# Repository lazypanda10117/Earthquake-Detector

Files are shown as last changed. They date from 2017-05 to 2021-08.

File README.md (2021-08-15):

## A simple and affordable earthquake detector

<br>

**Brief description of the project**:

We constructed an earthquake detector that can accurately detect earthquakes from affordable equipment, such as gyroscopes and accelerometers. Our core detector and visualization code are written in C (Arduino) and Java (Processing) respectively, while the circuit is designed using Fritzing. These data are stored digitally and analyzed in real-time, which can then be visualized with our graph visualization software. If specific parameters from the analysis are satisfied, the detector will automatically alert people in the surroundings by sounding an alarm. Details about the background, implementation, and cost can be found in the technical report.

<br>

**Technical report**:

[Link to technical report](Report/technical%20report.pdf)

<br>

**Demo**:

Earthquake Detector Demo (http://www.youtube.com/watch?v=r_JWGgkC840 "Earthquake Detector Demo")

<br>

**Contributor**: 

Jeffrey Kam, Joseph Kwon, and Woojin Choi.

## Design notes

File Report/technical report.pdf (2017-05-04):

Earthquake Detector Report Members: Yongjun Kwon, Ho Yin Kam, Woojin Choi Mentor: Brian Mellon

Aim:
Construct an earthquake detector that can detect an earthquake, output the corresponding magnitude of it using a combination of gyroscope and accelerometer data, storing the data digitally, and alert people in the surrounding autonomously.

Abstract:
Researches have been conducted that ants were able to detect an earthquake with the change in gas emission (Hydrogen and Rodon) or by electromagnetic waves. We delved into this topic for further information and how the detection mechanism works. Although there are few significant papers regarding this subject, there are not enough data to reach a conclusion of such mechanism and the research is not able to show a cause and effect relation between gas anomaly and earthquake yet (only correlation has been illustrated). While the research on ants may not be statistically significant for our earthquake detection use, we were inspired by another research conducted by UC Berkeley about using mobile devices to create a distributed network for earthquake detection. As a result, we have resorted to using accelerometer and gyroscope combination to determine the presence of earthquake as we find this way more accurate, cost effective, and intuitive.

Apparatus:
Hardware and Electronics:
Arduino Uno
Arduino Nano
MPU6050 DMP6 (3-Axis Accelerometer and 3-axis gyroscope) GROVE buzzer
3 LED light (Red, Yellow, and Green)
Alwaysoff Vibration Switch (SW-420)
Real Time Clock Module (DST3231)
SD Card Module
Bluetooth Module (HC-05)
Wooden Case (13 cm by 14 cm by 10 cm)

Software:
Arduino Nano software that saves data to sd card and transmits data to computer through Bluetooth module
Arduino Uno software that retrieves data from the MPU6050 and associates the data with the actual data retrieval time using a realtime clock module
Website in javascript that displays the data in graph form.

Documentation/Procedure:
A | working | prototype | is | shown | in | the | following | link:
https://drive.google.com/a/ais.edu.hk/file/d/0B9tS-JHjEeC7NWtzNWlVLTgwYlU/view?usp=drivesdk (https://drive.google.com/a/ais.edu.hk/file/d/0B9tS-JHjEeC7NWtzNWlVLTgwYlU/view?usp=drivesdk)

Electrical Design:
We had to use different hardware materials to finish this earthquake detector and used the Nano Arduino as the mainframe to act and gain data of various components of the machine.The program made for the nano to get the gyroscope/accelerometer was to serve as a motion detector and data to get the roll, yaw, and pitch. The Real Time Clock was used to get the difference in time as milliseconds. The vibrator switch detected if there was a vibration and triggers the buzzer and the LEDs to turn on if the vibration is in accordance with the accelerometer and gyroscope sensor. (i.e. if there is a spike in gyroscope data, it may be some noise or interference. But if we combine with a vibration switch, we can clearly see if the data is a false alarm or not.)

Circuit Board Design:
We have designed a circuit that integrates our whole system into one unified board. This way allow us to organise our connections better and also prevents unexpected errors, such as malfunctioning and loose wires. The top right is the SD card component, connecting to the top
Arduino. The bottom right consists of 4 LEDs,
which are indicators for power, vibration switch,

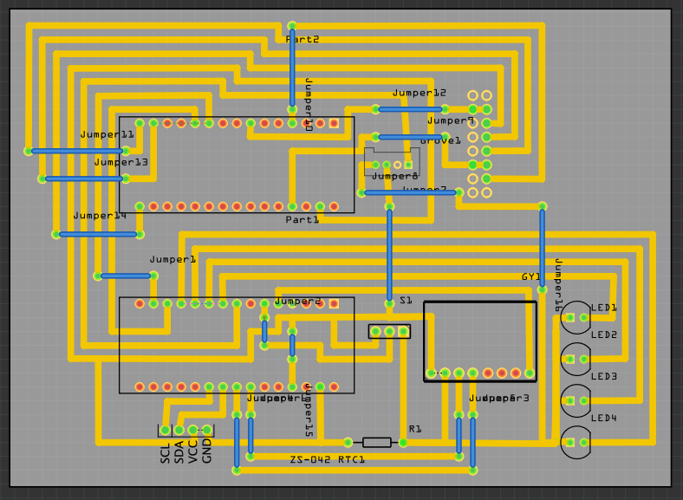
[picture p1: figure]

gyroscope/accelerometer, and earthquake. Next to the LEDs is the MPU 6050, which is connected to the bottom Arduino. The bottom Arduino is attached to the Real Time Clock right below it. After every iteration of code, the data will be compiled and send to the top Arduino using Software Serial using port 10 and 11 and a common GND. The buzzer is connected to the bottom Arduino, so when our program concluded that there might be an earthquake, it will be activated.

Mechanical Design:
We have decided to make a wooden box to put the earthquake detector in because we wouldn't want the machinery to break. The box was made in Maker Bay, a company that sponsored our team. With their contribution, we are able to make a box with their tools for the earthquake detector. All components in the earthquake detector will be placed in the box except the LEDs. With that in mind, we construct a 13x14x10 centimetre wooden box. We made the box by cutting wooden pieces with a blade saw, installing angle connectors, adjusting the box to the right size and sandpapering the box.

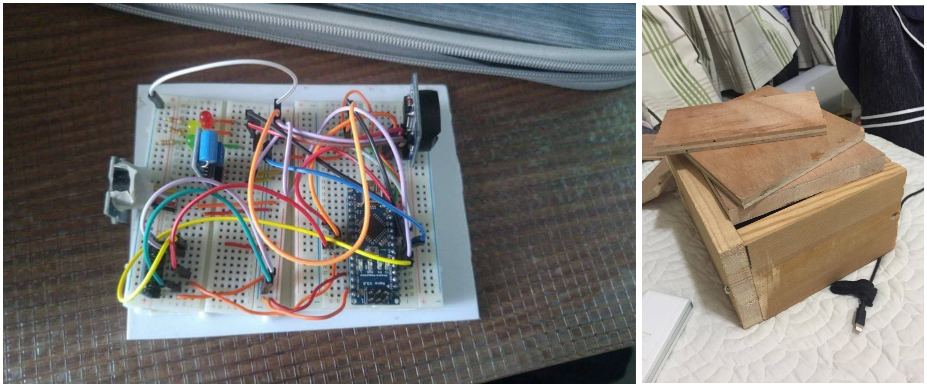
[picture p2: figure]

Software Design
The software is separated into 2 section: the data retrieval and compilation, and the data storing and sending. Mentioned above, we are using two Arduino in our detection system. The two Arduino are connected for data transmission in this following format (time, yaw, pitch, roll, accelerometer x,y,z, average derivative for yaw, pitch roll, x,y,z, magnitude calculated from gyroscope data, magnitude calculated from accelerometer data). The reason we have to separate the system into two Arduino is that Arduino nano does not have enough processing power and ram to run all the calculations regarding the earthquake magnitude, and not enough space to store all the data in our 12 arrays, each storing 12 data entry. Also, even if the board is switched to Arduino Uno, the calculation, data retrieval, and time retrieval take around 0.01-0.03 milliseconds to process, which creates a lot of trouble when we try to log our data as the time will be accumulatively more inaccurate. To transfer data from the Arduino UNO to Arduino nano, we used an internal protocol called the Software Serial, allowing us to transmit around 100 bytes of data every 0.08 seconds. We choose this over I2C for data transmission because I2C has an inherent limitation of 32-bytes of data transferal.

Data retrieval and compilation
We retrieve the data from MPU 6050 using the standardized I2C protocol. When the sensor is first initialized, it is really unstable, so we have devised a code to check the stability of the sensor. If the sensor is stable, the program then continue to retrieve data from our sensors and real time clock; If not, the program will keep looping until the sensor reaches data stability. During data retrieval, we store our data gyroscope yaw, pitch, roll, accelerometer x,y,z, into 6 arrays of length 12. We then calculate the derivative (changes) in between each previous data points, and generate another 6 arrays of length 12 that stores all these calculated derivatives. All these data will be passed through a function that calculates the average value of the array and this value will be sent to another function that determines the magnitude of the earthquake based on our empirically defined constants (shown in “How to measure data and calculate magnitude” section). If this value passes a certain threshold that we define, and this spike of change corresponds to data collected from the vibration switch, we will conclude that there is an earthquake and activate the LEDs and buzzer. A picture of the core algorithm of the program is shown below.

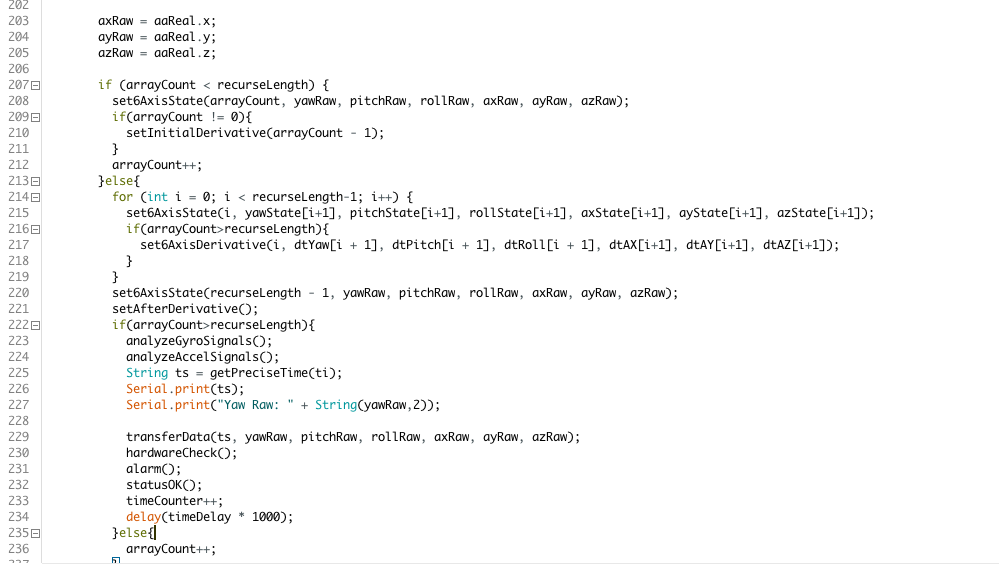
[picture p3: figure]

Data storing and sending
This code is on the top Arduino, running recursively to retrieve all the raw data and calculated derivative arrays from the bottom Arduino. We will first run a preliminary check on the data to make sure the data received are accurate and not some random signal noise. To ensure the integrity of data, we send it in a particular format so that when the program checks the pattern and if it doesn't match, that whole iteration of data entry will be disregarded in our storing process. These data will be compressed and reduced before storing because according to our calculation, we would need an 8gb SD card every month as it generates approximately 300 MB per day. We reduced the data only to have the raw data values and the time of data entry as the derivatives and magnitude can be calculated onthefly as the computer crunches through these massive amounts of data. Through this, we can reduce approximately 60% of the data sent, thus profoundly improving the usability of our system. After storing data, these entries will be broadcasted to the surrounding through Bluetooth using the HC-05 module. A computer can read these data in real time through its internal Bluetooth serial and make use of these realtime data (such as creating a graph of the data or instantaneously send warning to family members).

How to measure data and calculate magnitude:
A | demo | of | the | data | calculation | is | shown | here:
https://drive.google.com/file/d/0B9tS-JHjEeC7X1VtSnVrNmxDQzg/view?usp=sharing (https://drive.google.com/file/d/0B9tS-JHjEeC7X1VtSnVrNmxDQzg/view?usp=sharing)

We measure our data using the MPU 6050 sensors. After data is received and processed (calculating derivative array and average array value), we calculate the earthquake magnitude using the equation:

average derivative = ke

| | | | c(magnitude)

We can rearrange the equation and calculate the average magnitude from our data by changing the formula to:

k

average magnitude = e
c(magnitude)
ln( | ) | (magnitude)
k

average magnitude = c

agnitude
c
ln( | )
k

average magnitude
= m

We devised this equation based on the idea of Richter scale, a logarithmic scale for quantizing the strength of earthquake. We used a combination of some test data and online researches to determine exponential regression line, and use it to find the constants c and k for our equation.

Conclusion
The prototype shows a new and efficient way to detect the earthquake. We used the gyroscope/accelerometer because it is a much efficient way to make data than that of seismographs. We would be able to use a quake alarm where they alarm when an earthquake is coming. However, it can only approximate the magnitude of earthquake based on our limited testing. Based on this approximate magnitude, we can thus estimate how much damage it had caused. This earthquake detector is also economical to build. Researchers has used laser beams and different instruments for the construction of such detector, which are expensive, yet our whole system has only cost us a mere 156 HKD.

Cost:

Item | Cost
Arduino Nano/ uno | 100 HKD
Buzzer | 5 HKD
Accelerometer | 8 HKD
4 LED light | 1 HKD
SD card | 2 HKD
Real Time Clock | 6 HKD
Bluetooth Module | 20 HKD
Vibration Detector | 8 HKD
Circuit board | 6 HKD
Total | 156 HKD

Acknowledgement:
We would like to give special thanks to the following people/ company who have supported us during the course of this competition.
Eunsup Kang
Brian Mellon
Justin Bae
MakerBay

Reference:
December 07, 2010 | 20 Comments. "Earthquake Data Logger." Earthquake Data Logger
SparkFun | Electronics. | N.p., | n.d. | Web. | 24 | Apr. | 2017
<. https://www.sparkfun.com/tutorials/235 >.
"Earthquake Indicator Using Arduino Page 2 of 2." Electronics For You. N.p., 02 Feb. 2017.
Web. | | | 24 | | | Apr. | | | | 2017.
< http://electronicsforu.com/electronicsprojects/hardwarediy/arduinoearthquakeindicator/2 >.
Veedo. "Arduino Seismic Activity Monitor Ethernet Shield." Instructables.com.
Instructables, | 12 | May | 2016. | Web. | 24 | Apr. | 2017.
< http://www.instructables.com/id/Arduino-Seismic-Activity-Monitor-Ethernet-Shield/?ALLS TEPS (http://www.instructables.com/id/Arduino-Seismic-Activity-Monitor-Ethernet-Shield/?ALLSTEPS) >
"Measuring the Size of an Earthquake." U.S. Geological Survey. N.p., n.d. Web. 24 Apr. 2017. < https://earthquake.usgs.gov/learn/topics/measure.php >.
"Hong Kong Observatory." Modified Mercalli Scale. N.p., n.d. Web. 24 Apr. 2017. < http://www.hko.gov.hk/gts/equake/mms_e.htm >.
Berberich, Gabriele, Martin Berberich, Arne Grumpe, Christian Wöhler, and Ulrich Schreiber. "Early Results of Three-Year Monitoring of Red Wood Ants' Behavioral Changes and Their Possible Correlation with Earthquake Events." MDPI. Multidisciplinary Digital
Publishing | Institute, | 04 | Feb. | 2013. | Web. | 24 | Apr. | 2017.
< http://www.mdpi.com/2076-2615/3/1/63/htm (http://www.mdpi.com/2076-2615/3/1/63/htm) >.
"Can Ants Predict When an Earthquake Will Strike?" Local Weather from AccuWeather.com
| Superior | Accuracy™. | N.p., | n.d. | Web. | 24 | Apr. | 2017.
< http://www.accuweather.com/en/weathernews/canantspredictwhenanearth/10211815 (http://www.accuweather.com/en/weather-news/can-ants-predict-when-an-earth/10211815) >. Oskin, Becky. "Ants Lead the Way on Earthquake Prediction." N.p., 11 Apr. 2013. Web. 24 Apr. 2017. < http://www.livescience.com/28672-antssenseearthquakes.html (http://www.livescience.com/28672-ants-sense-earthquakes.html) >.
Zöller, Gert, Sebastian Hainzl, and Jürgen Kurths. "Observation of growing correlation length as an indicator for critical point behavior prior to large earthquakes." Journal of Geophysical
Research: | Solid | Earth. | N.p., | 10 | Feb. | 2001. | Web. | 24 | Apr. | 2017.
< http://onlinelibrary.wiley.com/doi/10.1029/2000JB900379/full >.

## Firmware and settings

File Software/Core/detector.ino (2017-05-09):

#include <SD.h>
#include <SPI.h>
#include "I2Cdev.h"
#include "Wire.h"
#include <RTClib.h>
#include <SoftwareSerial.h>
#include "MPU6050_6Axis_MotionApps20.h"

RTC_DS3231 rtc;
MPU6050 mpu;

#define INTERRUPT_PIN 2

const int buzzerPin = 5;
const int orangeLedPin = 6;
const int greenLedPin = 7;
const int redLedPin = 8;
const int yellowLedPin = 9;

// MPU control/status vars
volatile bool mpuInterrupt = false;     // indicates whether MPU interrupt pin has gone high
bool dmpReady = false;  // set true if DMP init was successful
uint8_t mpuIntStatus;   // holds actual interrupt status byte from MPU
uint8_t devStatus;      // return status after each device operation (0 = success, !0 = error)
uint16_t packetSize;    // expected DMP packet size (default is 42 bytes)
uint16_t fifoCount;     // count of all bytes currently in FIFO
uint8_t fifoBuffer[64]; // FIFO storage buffer

// orientation/motion vars
Quaternion q;           // [w, x, y, z]         quaternion container
VectorInt16 aa;         // [x, y, z]            accel sensor measurements
VectorInt16 aaReal;     // [x, y, z]            gravity-free accel sensor measurements
VectorInt16 aaWorld;    // [x, y, z]            world-frame accel sensor measurements
VectorFloat gravity;    // [x, y, z]            gravity vector
float euler[3];         // [psi, theta, phi]    Euler angle container
float ypr[3];           // [yaw, pitch, roll]   yaw/pitch/roll container and gravity vector
float xyzAccel[3];    
const int accelG = 16384;
//own variables
float prevYpr[3];
float offsetYpr[3]; //initial positions
boolean stable = false;
boolean stableN = false;

double yawRaw;
double pitchRaw;
double rollRaw;

double axRaw;
double ayRaw;
double azRaw;

int arrayCount = 0;
const int recurseLength = 12;
double timeDelay = 0.08;
int timeCounter = 0;
int timeStackToUpload = 3;

long ti; //unix time
String tS; //string unix time
String sdTimeName = "";

double gyroAlarmThreshold = 1.5;
double accelAlarmThreshold1 = 3;
double accelAlarmThreshold2 = 3;
double accelAlarmThreshold3 = 3.8;

double yawState[recurseLength];
double pitchState[recurseLength];
double rollState[recurseLength];

double dtYaw[recurseLength];
double dtPitch[recurseLength];
double dtRoll[recurseLength];

double axState[recurseLength];
double ayState[recurseLength];
double azState[recurseLength];
//end of Setting MPU variables

//equation that model gyroscope magnitude: signal = ke^(c(magnitude))
double expConst = 0.4642; //c
double scaleConst = 1.5578; //k

//equation that model acceleration magnitude: magnitude = a + b(ln(signal))
double baseAccelConst = 7.66395201; //a
double scaleAccelConst = 0.7781699; //b

double mag[3] = {0, 0, 0};
double magA[3] = {0, 0, 0};
double avgD[3] = {0, 0, 0};
double avgA[3] = {0, 0, 0};

File logFile;

void dmpDataReady() {
  mpuInterrupt = true;
}

void setup() {
#if I2CDEV_IMPLEMENTATION == I2CDEV_ARDUINO_WIRE
  Wire.begin();
#elif I2CDEV_IMPLEMENTATION == I2CDEV_BUILTIN_FASTWIRE
  Fastwire::setup(400, true);
#endif
  Serial.begin(115200);
  Serial3.begin(9600);
  if (! rtc.begin()) {
    Serial.println("RTC Failed");
    while (1);
  }
  if (rtc.lostPower()) {
    Serial.println("RTC Failed");
    rtc.adjust(DateTime(F(__DATE__), F(__TIME__)));
  }
  DateTime now = rtc.now();
  sdTimeName = "E";
  String sm = String(now.month());
  if(now.month() < 10){
    sm = "0" + sm;
  }
  String sd = String(now.day());
  if(now.day() < 10){
    sd = "0" + sd;
  }
  sdTimeName += String(now.year()).substring(2,4);
  sdTimeName += sm;
  sdTimeName += sd;
  if (!SD.begin(4)) {
    Serial.println("SD error");
    return;
  }
  mpu.initialize();
  pinMode(INTERRUPT_PIN, INPUT);
  pinMode(buzzerPin, OUTPUT);
  pinMode(yellowLedPin, OUTPUT);
  pinMode(redLedPin, OUTPUT);
  pinMode(greenLedPin, OUTPUT);
  Serial.println(F("Connecting"));
  Serial.println(mpu.testConnection() ? F("Success") : F("Failed"));
  devStatus = mpu.dmpInitialize();
  mpu.setXGyroOffset(220);
  mpu.setYGyroOffset(76);
  mpu.setZGyroOffset(-85);
  mpu.setZAccelOffset(1788);
  if (devStatus == 0) {
    mpu.setDMPEnabled(true);
    attachInterrupt(digitalPinToInterrupt(INTERRUPT_PIN), dmpDataReady, RISING);
    mpuIntStatus = mpu.getIntStatus();
    Serial.println(F("Start"));
    dmpReady = true;
    packetSize = mpu.dmpGetFIFOPacketSize();
  } else {
    Serial.println("MPU Failed");
  }
  for (int i = 0; i < 3; i++) {
    prevYpr[i] = 9999;
  }
}

void loop() {
    if (!dmpReady) return;
    mpuInterrupt = false;
    mpuIntStatus = mpu.getIntStatus();
    fifoCount = mpu.getFIFOCount();
    if ((mpuIntStatus & 0x10) || fifoCount == 1024) {
      mpu.resetFIFO();
    }else if (mpuIntStatus & 0x02) {
      while (fifoCount < packetSize) fifoCount = mpu.getFIFOCount();
      mpu.getFIFOBytes(fifoBuffer, packetSize);
      fifoCount -= packetSize;
      mpu.dmpGetQuaternion(&q, fifoBuffer);
      mpu.dmpGetGravity(&gravity, &q);
      mpu.dmpGetAccel(&aa, fifoBuffer);
      mpu.dmpGetLinearAccel(&aaReal, &aa, &gravity);
      mpu.dmpGetYawPitchRoll(ypr, &q, &gravity);
      if (stable) {      
        yawRaw = ypr[0] * 180 / M_PI;
        pitchRaw = ypr[1] * 180 / M_PI;
        rollRaw = ypr[2] * 180 / M_PI;
        axRaw = aaReal.x-430;
        ayRaw = aaReal.y;
        azRaw = aaReal.z;
        if (arrayCount < recurseLength) {
          set6AxisState(arrayCount, yawRaw, pitchRaw, rollRaw, axRaw, ayRaw, azRaw);
          if(arrayCount != 0){
            setInitialDerivative(arrayCount - 1);
          }
          arrayCount++;  
        }else{
          for (int i = 0; i < recurseLength-1; i++) {
            set6AxisState(i, yawState[i+1], pitchState[i+1], rollState[i+1], axState[i+1], ayState[i+1], azState[i+1]);
            if(arrayCount>recurseLength){
              set3AxisDerivative(i, dtYaw[i + 1], dtPitch[i + 1], dtRoll[i + 1]);
            }
          }
          set6AxisState(recurseLength - 1, yawRaw, pitchRaw, rollRaw, axRaw, ayRaw, azRaw);
          setAfterDerivative();
          if(arrayCount>recurseLength){
            analyzeGyroSignals();
            analyzeAccelSignals();
            String ts = getPreciseTime(ti);
            transferData(ts, yawRaw, pitchRaw, rollRaw, axRaw, ayRaw, azRaw);
            if(!stableN){
              if(magA[1] < 2.5 && magA[2] < 3.5){
                stableN = true;
              }
            }else{
              alarm();
              statusStable();
            }
            statusOK();
            timeCounter++;
            delay(timeDelay * 1000);
          }else{
            arrayCount++;  
          }
        }
        
      } else {
        if (abs(prevYpr[0] - (ypr[0] * 180 / M_PI)) <= 0.01 && abs(prevYpr[1] - (ypr[1] * 180 / M_PI)) <= 0.01 && abs(prevYpr[2] - (ypr[2] * 180 / M_PI)) <= 0.01) {
          delay(3000);
          if (abs(prevYpr[0] - (ypr[0] * 180 / M_PI)) <= 0.01 && abs(prevYpr[1] - (ypr[1] * 180 / M_PI)) <= 0.01 && abs(prevYpr[2] - (ypr[2] * 180 / M_PI)) <= 0.01) {
              Serial.println(ayRaw);
              stable = true;
              for (int i = 0; i < 3; i++) {
                offsetYpr[i] = ypr[i] * 180 / M_PI;
              }
              while(aaReal.y > 60 && aaReal.z > 60){
                delay(50);
              }
          }
        } else {       
          prevYpr[0] = ypr[0] * 180 / M_PI;
          prevYpr[1] = ypr[1] * 180 / M_PI;
          prevYpr[2] = ypr[2] * 180 / M_PI;         
          delay(50);
        }
      }
    }
}

void statusStable(){
  digitalWrite(orangeLedPin,HIGH);
}

void analyzeGyroSignals() {
  //average last recureseLength d(angle)/dt to see which range it is in
  double tempVal1 = 0;
  avgD[0] = averageDerivative(dtYaw);
  avgD[1] = averageDerivative(dtPitch);
  avgD[2] = averageDerivative(dtRoll);
  for (int i = 0; i < 3; i++) {
    tempVal1 = gyroEquation(avgD[i]);
    mag[i] = tempVal1;
  }
}

double gyroEquation(double d){
  return (log((d/scaleConst)+1) / expConst);
}

void analyzeAccelSignals(){
  double tempVal2 = 0;
  avgA[0] = averageDerivative(axState);
  avgA[1] = averageDerivative(ayState);
  avgA[2] = averageDerivative(azState);  
  for (int i = 0; i < 3; i++) {
    tempVal2 = accelEquation(avgA[i]);
    magA[i] = tempVal2;
  }
}

double accelEquation(double d){
  double tD = d/(double)accelG;
  return baseAccelConst + (scaleAccelConst*log(tD));
}

void setInitialDerivative(int i) {
  dtYaw[i] = yawState[i + 1] - yawState[i];
  dtPitch[i] = pitchState[i + 1] - pitchState[i];
  dtRoll[i] = rollState[i + 1] - rollState[i];
}

void setAfterDerivative() {
  dtYaw[recurseLength - 1] = yawState[recurseLength - 1] - yawState[recurseLength - 2];
  dtPitch[recurseLength - 1] = pitchState[recurseLength - 1] - pitchState[recurseLength - 2];
  dtRoll[recurseLength - 1] = rollState[recurseLength - 1] - rollState[recurseLength - 2];
}

void set6AxisState(int id, double y, double p, double r, double ax, double ay, double az) {
  yawState[id] = y;
  pitchState[id] = p;
  rollState[id] = r;
  axState[id] = ax;
  ayState[id] = ay;
  azState[id] = az;
}

void set3AxisDerivative(int id, double dy, double dp, double dr) {
  dtYaw[id] = dy;
  dtPitch[id] = dp;
  dtRoll[id] = dr;
}

double averageDerivative(double d[]) {
  double total = 0;
  for (int i = 0; i < recurseLength; i++) {
    total += abs(d[i]);
  }
  return total / (double)recurseLength;
}

void transferData(String preciseTime, double y, double p, double r, double ax, double ay, double az) {
  String tS = "{" + preciseTime + "," + String(y,2) + "," + String(p,2) + "," + String(r,2) + "," + String(mag[0],2) + "," + String(mag[1],2) + "," + String(mag[2],2) + "," + String(ax,2) + "," + String(ay,2) + "," + String(az,2) + "," + String(magA[0],2) + "," + String(magA[1],2) + "," + String(magA[2],2)+"}";
  String tP =  "{" + preciseTime + "," + String(mag[0],2) + "," + String(mag[1],2) + "," + String(mag[2],2) +  "," + String(magA[0],2) + "," + String(magA[1],2) + "," + String(magA[2],2)+"}";
  //String tA =  "{" + preciseTime + "," + String(magA[0],2) + "," + String(magA[1],2) + "," + String(magA[2],2)+"}";

  if(timeCounter%((int)((timeStackToUpload*100)/(int)(100*timeDelay))) == 0){
    DateTime now = rtc.now();
    ti = now.unixtime();
    timeCounter=0;
  }
  Serial.println(tP);
  Serial3.println(tP);
  putToSDCard(tS);
}

void statusOK() {
  digitalWrite(greenLedPin, HIGH);
}

boolean gyroAlarmCheck() {
  if (mag[0] >= gyroAlarmThreshold || mag[1] >= gyroAlarmThreshold || mag[2] >= gyroAlarmThreshold) {
    digitalWrite(yellowLedPin, HIGH);
    return true;
  }else{
    digitalWrite(yellowLedPin, LOW);
    return false;
  }

}

boolean accelAlarmCheck(){
  if (magA[0] >= accelAlarmThreshold1 || magA[1] >= accelAlarmThreshold2 || magA[2] >= accelAlarmThreshold3){
    digitalWrite(redLedPin, HIGH);
    return true;
  }else{
    digitalWrite(redLedPin, LOW);
    return false;
  }
}

void alarm(){
  boolean a = accelAlarmCheck();
  boolean b = gyroAlarmCheck();
  if(a || b){
    digitalWrite(buzzerPin,HIGH);
  }else{
    digitalWrite(buzzerPin,LOW);
  }
}

String getPreciseTime(long t){
  String tempS = String(t);
  String condition0 = "";
  char cA1[8];
  char cA2[4];
  (tempS.substring(3,10)).toCharArray(cA1,8);
  (tempS.substring(0,3)).toCharArray(cA2,4);
  long tempL1 = atol(cA1);
  int tempL2 = atol(cA2);
  if(tempS.charAt(3) == '0'){
    condition0 = "0";
  }
  long temp = (tempL1*100)+(long)(1.51*(timeDelay*100*timeCounter));
  String tempST = String(temp);
  if(tempST.charAt(0) == '1'){
    tempL2 += 1;
    tempST = tempST.substring(1,10);
  }
  int lenOfTST = tempST.length();
  String finalS = String(tempL2) + condition0 + tempST.substring(0,lenOfTST-2) + "." + tempST.substring(lenOfTST-2,lenOfTST);
  return finalS;
}

void putToSDCard(String s){
  String fileName = sdTimeName + ".txt";
  logFile = SD.open(fileName, FILE_WRITE);
  if (logFile) {
    logFile.println(s);
    logFile.close();
  }else{
    Serial.println("error opening logfile.txt");
  }
}

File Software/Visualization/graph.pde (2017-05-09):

import processing.serial.*;
Serial myPort;  
//PShape square;  
String prev0 = "";
double prev1 = 0;
double prev2 = 0;
double prev3 = 0;
double prev4 = 0;
double prev5 = 0;
double prev6 = 0;
String p0 = "";
double p1 = 0;
double p2 = 0;
double p3 = 0;
double p4 = 0;
double p5 = 0;
double p6 = 0;
double segment = 150;
int widthL = 1280;
int lengthL = 720;
int count = 0;

int midA = (lengthL/4);
int maxA = 10;
int scaleA = midA/maxA;

int midG = 3*(lengthL/4);
int maxG = 8;
int scaleG = midA/maxA;

void setup(){
  //printArray(Serial.list());
  myPort = new Serial(this, Serial.list()[7], 115200);
  size(1280,720);
  background(255);
  stroke(150);
  strokeWeight(3);
  line(0,lengthL/2, widthL, lengthL/2);
  strokeWeight(1);
  line(0,lengthL/4, widthL, lengthL/4);  
  line(0,3*(lengthL/4), widthL, 3*(lengthL/4));  
  fill(0);
  textSize(12);
  text("Unix Time (s): ", 0, 20);
}

void draw(){
  while (myPort.available() > 0) {
    String inBuffer = "";
    char c = myPort.readChar();
    inBuffer += c;
    while(c!='}' && myPort.available() > 0){
      c = myPort.readChar();
      inBuffer += c;
    }
      try{
        if(inBuffer.charAt(0) == '{'){
          String tempS = inBuffer.substring(1,inBuffer.length()-1);
          String sa[] = split(tempS,",");
          p0 = sa[0];
          p1 = Double.parseDouble(sa[1]);
          p2 = Double.parseDouble(sa[2]);
          p3 = Double.parseDouble(sa[3]);
          p4 = Double.parseDouble(sa[4]);
          p5 = Double.parseDouble(sa[5]);
          p6 = Double.parseDouble(sa[6]);
          plotGraph(p0, p1,p2,p3,p4,p5,p6,count);
          prev0 = p0;
          prev1 = p1;
          prev2 = p2;
          prev3 = p3;
          prev4 = p4;
          prev5 = p5;
          prev6 = p6;
        }
      }catch(Exception e){
        plotGraph(prev0, prev1,prev2,prev3,prev4,prev5,prev6,count);
      }
      
      println(inBuffer);
    }
  if(count%2 == 0){
    noStroke();
    fill(255);
    rect(0 + textWidth("Unix Time (s): "),10,textWidth("1231231231231.14"),14);
  }
  if(count > segment){
    background(255);
    stroke(150);
    strokeWeight(3);
    line(0,lengthL/2, widthL, lengthL/2);
    strokeWeight(1);
    line(0,lengthL/4, widthL, lengthL/4);  
    line(0,3*(lengthL/4), widthL, 3*(lengthL/4));
    fill(0);
    textSize(12);
    text("Unix Time (s): ", 0, 20);
    count = 0;
  }
}

void plotGraph(String t, double a, double b, double c, double d, double e, double f, int g){

  fill(0);
  textSize(12);
  text(t,0 + textWidth("Unix Time (s): "), 20);
  //println(t);
  double x1 = (g-1)*((double)widthL/segment);
  double x2 = g*((double)widthL/segment);

  strokeWeight(1.2);
  //gyroscope
  stroke(204, 102, 0); //red
  line((float)x1,(float)(midA-scaleA*prev1),(float)x2,(float)(midA-scaleA*a));
  stroke(150, 230, 128); //green 
  line((float)x1,(float)(midA-scaleA*prev2),(float)x2,(float)(midA-scaleA*b));
  stroke(0, 143, 134); //blue
  line((float)x1,(float)(midA-scaleA*prev3),(float)x2,(float)(midA-scaleA*c));
  //accelerometer
  stroke(204, 102, 0); //red
  line((float)x1,(float)(midG-scaleG*prev4),(float)x2,(float)(midG-scaleG*d));
  stroke(150, 230, 128); //green
  line((float)x1,(float)(midG-scaleG*prev5),(float)x2,(float)(midG-scaleG*e));
  stroke(0, 143, 134); //blue
  line((float)x1,(float)(midG-scaleG*prev6),(float)x2,(float)(midG-scaleG*f));
  count++;
}

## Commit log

2017-05-04 Version 1 of software and report pushed. Web not finished
    [EarthquakeDetectorFinalV1.fzz]
2017-05-04 added circuits
    [earthquake detector v1.fzz, earthquake detector v2.fzz, earthquake detector v3.fzz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]
2017-05-07 version 3 code upload and also graph added
    [EarthquakeDetectorFinalCircuitV1.fzz]
2017-05-09 Graph with gyroscope magnitude data and previous value discontinuities fixed
    [graph.pde]
2021-08-15 Clean up and restructure
    [earthquake detector v1.fzz, earthquake detector v2.fzz, earthquake detector v3.fzz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]
